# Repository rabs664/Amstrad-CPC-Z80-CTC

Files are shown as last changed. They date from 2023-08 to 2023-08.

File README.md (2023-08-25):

# Amstrad CPC Z80 CTC
Simple Z80 CTC board compatible with the Amstrad CPC and MX4 connector.

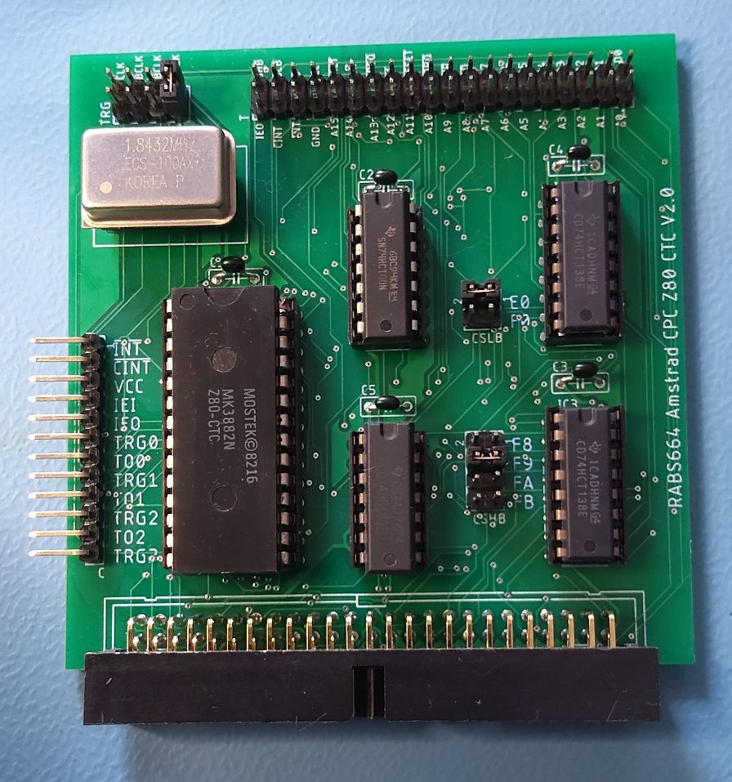
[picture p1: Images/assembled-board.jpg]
assembled-board


## Objective
Prototyping board to learn about the Z80 CTC, and how to write Z80 assembly using an Amstrad CPC.

## Background
Part of a number of modular cards using Z80 associated peripherals and the Amstrad CPC.

See also;
[Amstrad CPC 2855 PIO](https://github.com/rabs664/Amstrad-CPC-8255-PIO) and [Amstrad CPC Z80 DART](https://github.com/rabs664/Amstrad-CPC-Z80-DART)

## Backplane
[CPC Amstrad Expansion Backplane by revaldinho](https://github.com/revaldinho/cpc_ram_expansion/wiki/CPC-Expansion-Backplane)

## IO Addressing
The IO Address can be selected using two sets of jumpers (CS_HB and CS_LB), supporting the following base address.

* F8E0 and F8F0
* F9E0 and F9F0
* FAE0 and FAF0
* FBE0 and FBF0

See [CPC Wiki IO Port Summary](https://www.cpcwiki.eu/index.php/I/O_Port_Summary) for a list of known IO ports used on the Amstrad CPC.

## Testing
The Z80 CTC board has been built and simple testing has been completed on an Amstrad CPC 6128.

IEI was tied high (via a 10K resistor).

Test schematic using 74HCT74s is included in the images folder.

This board was also used to provide the Baud Clock for the [Amstrad CPC Z80 DART](https://github.com/rabs664/Amstrad-CPC-Z80-DART).

## PCBs
PCBs are available from [Seeed Studio](https://www.seeedstudio.com/Simple-Z80-CTC-board-compatible-with-the-Amstrad-CPC-and-MX4-connecto-g-1393846).

## Components
This [Digi-Key](https://www.digikey.co.uk/en/mylists/list/0Q38QB2P95) List contains all components excluding the Z80 CTC.

Note the right angled header for the port connections was not available at the time of producing this list but all other components were in stock for shipping immediately.

## Assembler
[RASM](https://github.com/EdouardBERGE/rasm)

## Resources
[Zed80 Website](http://zed80.com/Z80-RETRO/index_Home.html)

[CPCWiki](https://www.cpcwiki.eu/index.php/Main_Page)

Z80 Application by James W Coffron ISBN 0-89588-094-6

## Acknowledgements
[@revaldinho](https://github.com/revaldinho)

Don Prefontaine 

Peter Murray

[@EdouardBERGE](https://github.com/EdouardBERGE)

# Release History
## Version 2.0
* First Release

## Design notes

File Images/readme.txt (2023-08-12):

This folder contains some images of the Amstrad CPC Z80 CTC board.

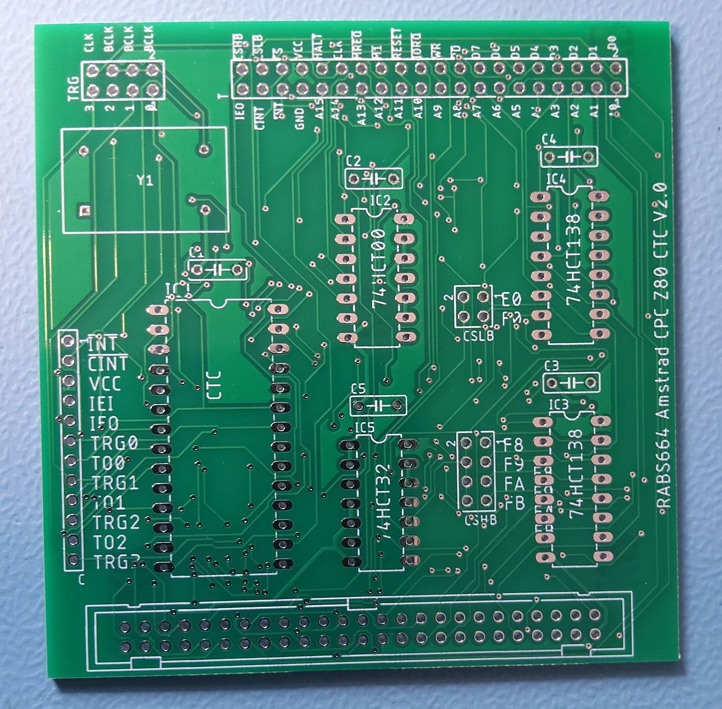
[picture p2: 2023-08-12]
Images/bare-board.jpg

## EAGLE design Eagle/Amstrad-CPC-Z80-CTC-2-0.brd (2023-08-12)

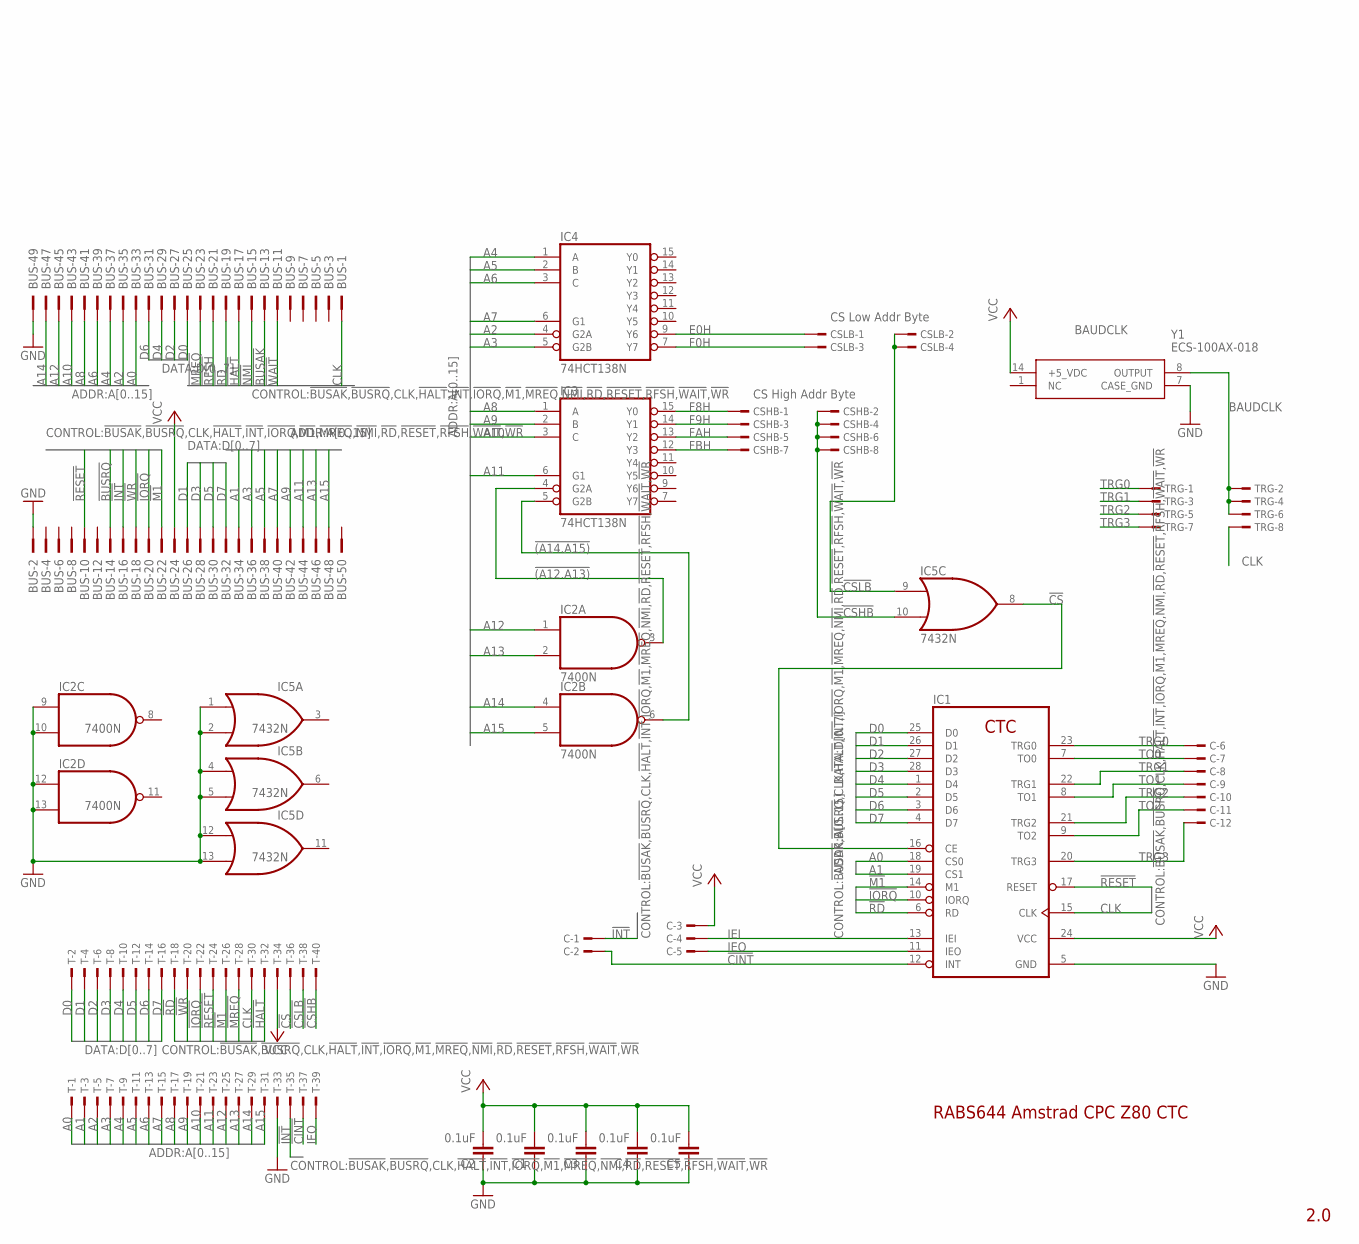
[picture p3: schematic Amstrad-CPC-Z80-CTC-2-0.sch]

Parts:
BUS: 2550-; PAK100/2500-50
C: TSW-112-07-G-S; TSW-112-XX-G-S
C1, C2, C3, C4, C5: 0.1uF; C050-025X075
CSHB: TSW-104-07-G-D; TSW-104-XX-G-D
CSLB: TSW-102-07-G-D; TSW-102-XX-G-D
IC1: Z80CTC; DIL28
IC2: 7400N; DIL14
IC3, IC4: 74HCT138N; DIL16
IC5: 7432N; DIL14
T: TSW-120-07-G-D; TSW-120-XX-G-D
TRG: TSW-104-07-G-D; TSW-104-XX-G-D
Y1: ECS-100AX-018; ECS100AX018

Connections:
!(A12.A13): IC2.3 (O), IC3.4 (G2A)
!(A14.A15): IC2.6 (O), IC3.5 (G2B)
!BUSAK: BUS.13
!BUSRQ: BUS.14
!CINT: C.2, IC1.12 (INT), T.37
!CS: IC1.16 (CE), IC5.8 (O), T.36
!CSHB: CSHB.2, CSHB.4, CSHB.6, CSHB.8, IC5.10 (I1), T.40
!CSLB: CSLB.2, CSLB.4, IC5.9 (I0), T.38
!HALT: BUS.17, T.32
!INT: BUS.16, C.1, T.35
!IORQ: BUS.20, IC1.10 (IORQ), T.22
!M1: BUS.22, IC1.14 (M1), T.26
!MREQ: BUS.23, T.28
!NMI: BUS.15
!RD: BUS.19, IC1.6 (RD), T.18
!RESET: BUS.10, IC1.17 (RESET), T.24
!RFSH: BUS.21
!WAIT: BUS.11
!WR: BUS.18, T.20
A0: BUS.33, IC1.18 (CS0), T.1
A1: BUS.34, IC1.19 (CS1), T.3
A2: BUS.35, IC4.4 (G2A), T.5
A3: BUS.36, IC4.5 (G2B), T.7
A4: BUS.37, IC4.1 (A), T.9
A5: BUS.38, IC4.2 (B), T.11
A6: BUS.39, IC4.3 (C), T.13
A7: BUS.40, IC4.6 (G1), T.15
A8: BUS.41, IC3.1 (A), T.17
A9: BUS.42, IC3.2 (B), T.19
A10: BUS.43, IC3.3 (C), T.21
A11: BUS.44, IC3.6 (G1), T.23
A12: BUS.45, IC2.1 (I0), T.25
A13: BUS.46, IC2.2 (I1), T.27
A14: BUS.47, IC2.4 (I0), T.29
A15: BUS.48, IC2.5 (I1), T.31
BAUDCLK: TRG.2, TRG.4, TRG.6, Y1.8 (OUTPUT)
CLK: BUS.1, IC1.15 (CLK), T.30, TRG.8
D0: BUS.25, IC1.25 (D0), T.2
D1: BUS.26, IC1.26 (D1), T.4
D2: BUS.27, IC1.27 (D2), T.6
D3: BUS.28, IC1.28 (D3), T.8
D4: BUS.29, IC1.1 (D4), T.10
D5: BUS.30, IC1.2 (D5), T.12
D6: BUS.31, IC1.3 (D6), T.14
D7: BUS.32, IC1.4 (D7), T.16
E0H: CSLB.1, IC4.9 (Y6)
F0H: CSLB.3, IC4.7 (Y7)
F8H: CSHB.1, IC3.15 (Y0)
F9H: CSHB.3, IC3.14 (Y1)
FAH: CSHB.5, IC3.13 (Y2)
FBH: CSHB.7, IC3.12 (Y3)
GND: BUS.2, BUS.49, C1.1, C2.1, C3.1, C4.1, C5.1, IC1.5 (GND), IC2.7 (GND), IC2.9 (I0), IC2.10 (I1), IC2.12 (I0), IC2.13 (I1), IC3.8 (GND), IC4.8 (GND), IC5.1 (I0), IC5.2 (I1), IC5.4 (I0), IC5.5 (I1), IC5.7 (GND), IC5.12 (I0), IC5.13 (I1), T.33, Y1.7 (CASE_GND)
IEI: C.4, IC1.13 (IEI)
IEO: C.5, IC1.11 (IEO), T.39
TO0: C.7, IC1.7 (TO0)
TO1: C.9, IC1.8 (TO1)
TO2: C.11, IC1.9 (TO2)
TRG0: C.6, IC1.23 (TRG0), TRG.1
TRG1: C.8, IC1.22 (TRG1), TRG.3
TRG2: C.10, IC1.21 (TRG2), TRG.5
TRG3: C.12, IC1.20 (TRG3), TRG.7
VCC: BUS.24, C.3, C1.2, C2.2, C3.2, C4.2, C5.2, IC1.24 (VCC), IC2.14 (VCC), IC3.16 (VCC), IC4.16 (VCC), IC5.14 (VCC), T.34, Y1.14 (+5_VDC)

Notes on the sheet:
2.0
RABS644 Amstrad CPC Z80 CTC
CS Low Addr Byte
CS High Addr Byte
BAUDCLK

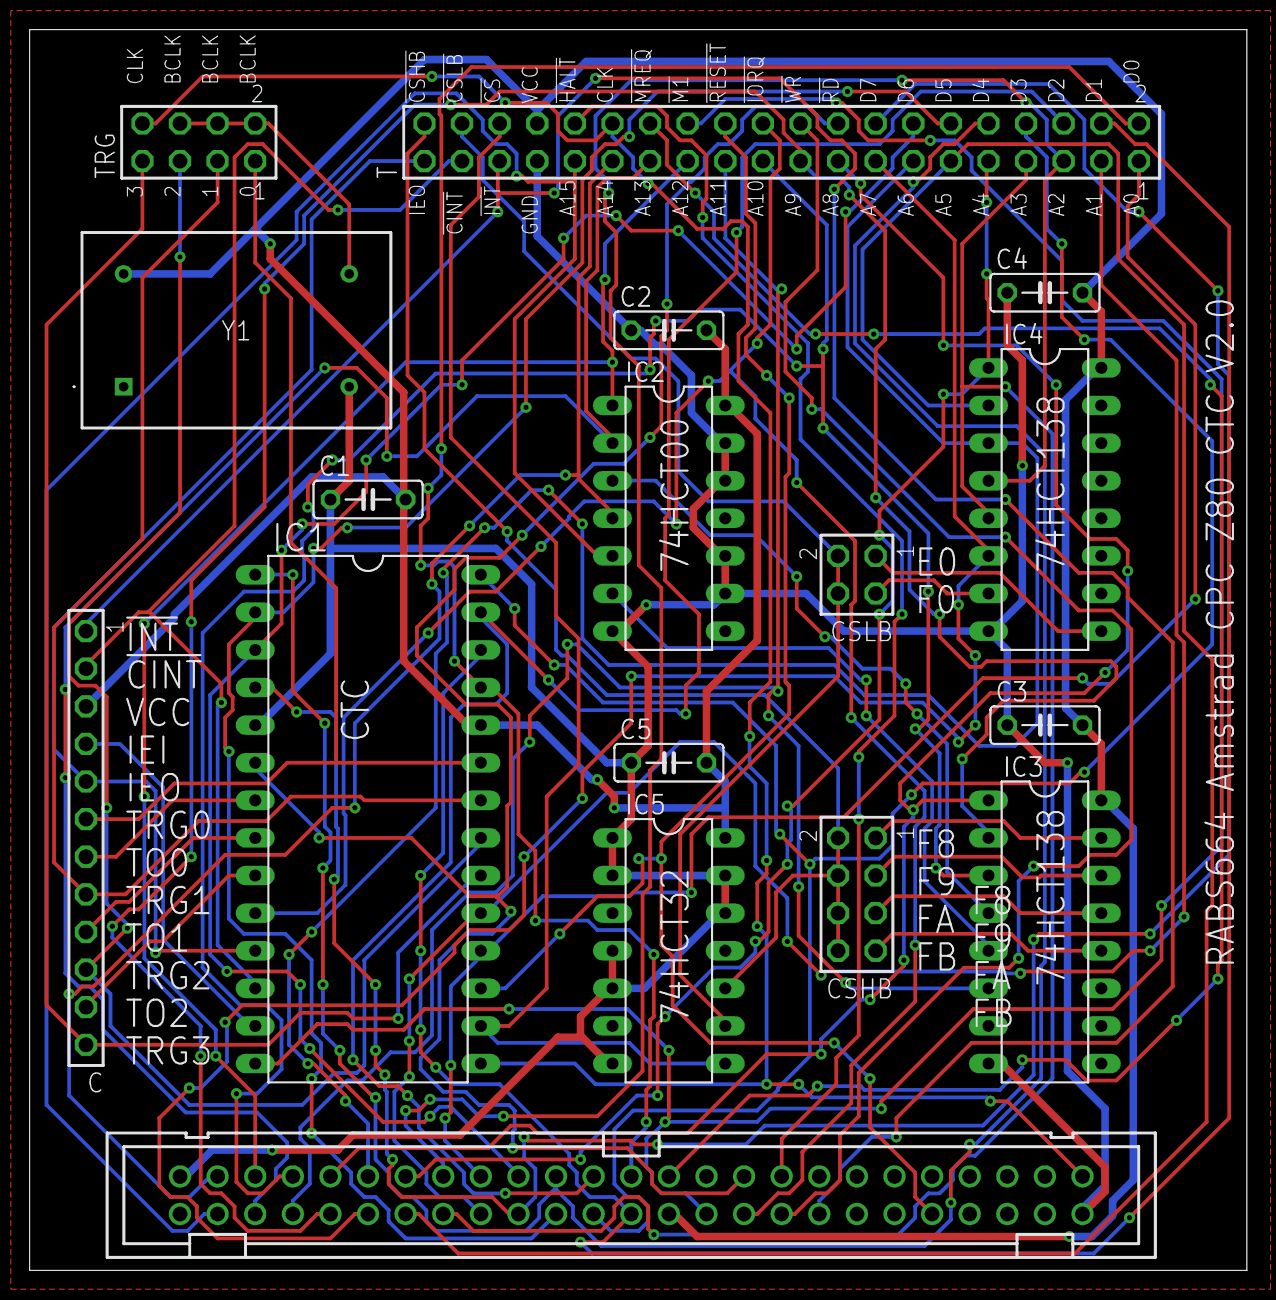
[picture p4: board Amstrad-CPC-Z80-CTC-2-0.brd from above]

Board: 2 copper layers, 82.2 x 83.8 mm, 17 parts (0 on the bottom side), 57 nets.

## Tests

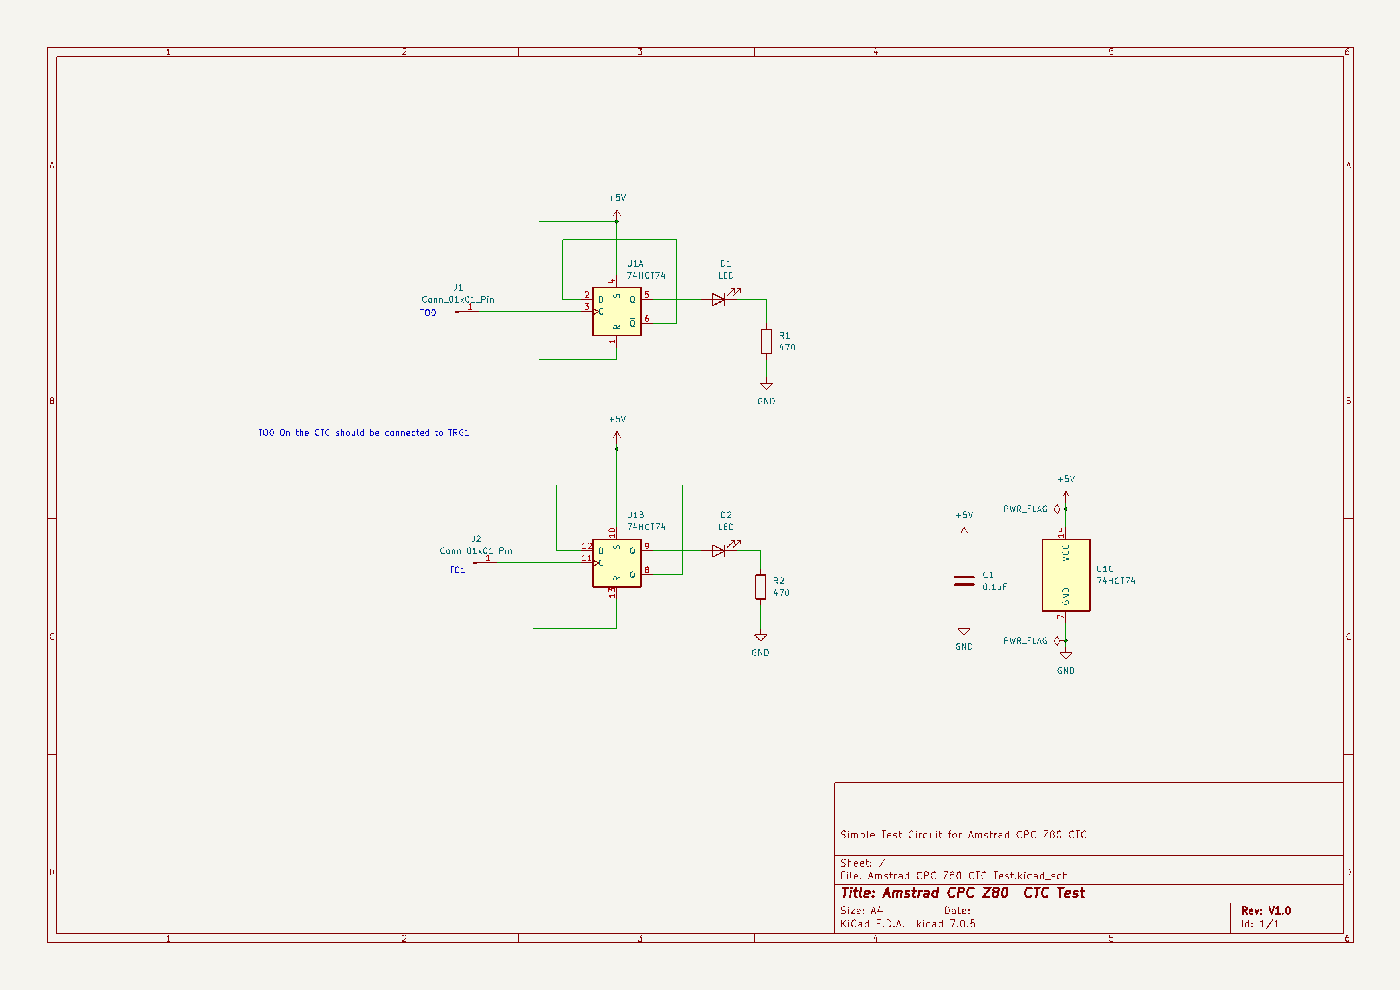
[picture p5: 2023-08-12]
Images/Amstrad-CPC-Z80-CTC-Test-SCH.png
